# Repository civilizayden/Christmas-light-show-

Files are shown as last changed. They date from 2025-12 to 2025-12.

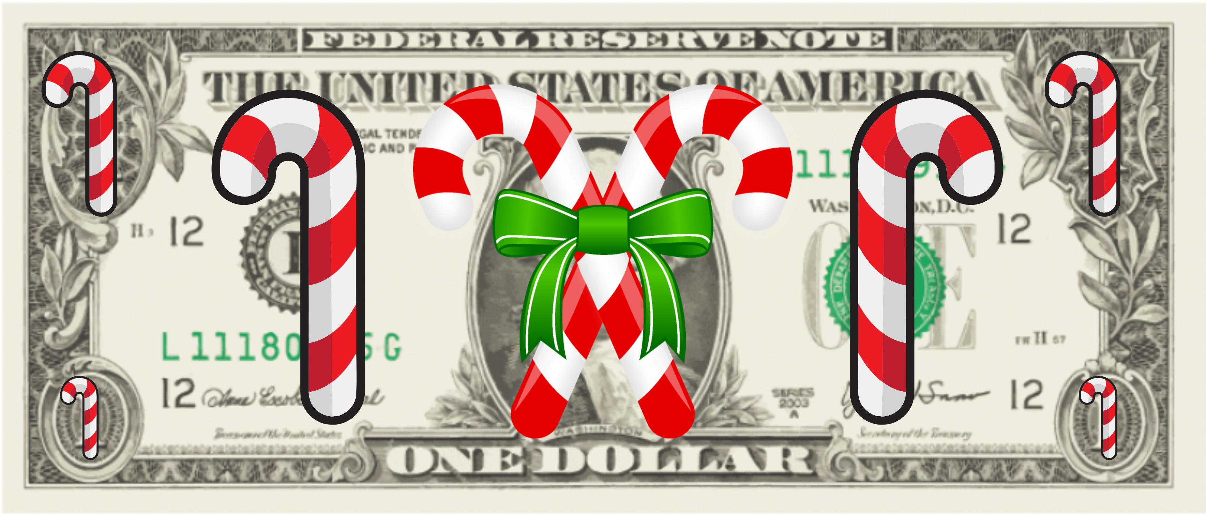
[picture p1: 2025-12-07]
Layout and Xlights config/ImportedMedia/The Elf Song/Images/Candy Cane Wages.png

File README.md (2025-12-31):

# Christmas light show
Light show  
Demo Video: https://youtu.be/NAZE_Fds844

# Description
5000 ws2811 pixels all synced to Christmas Music broadcasting over a radio transmitter. Includes 8 150 pixel candy canes, 3 talking coro props, 12 vertical strips outlining the house, pixels lining both the upper and lower eaves, 3 arches, 3 misc. coro props, and more. This year, there are 6 songs and intros to go along with them. Check out the rest of the info on the first journal entry on Blueprint! https://blueprint.hackclub.com/projects/2889 
# Files
I made all of the 3D files in onshape. Here's the links. I also uploaded them in .STEP format if you prefer that.  
  
WS2811 C9 clip-on: https://cad.onshape.com/documents/8e1d7c661a392a3fe8e3e552/w/2b79da62459af95523f34f54/e/d7efcc39778d9abc5af3c911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  
  
Vinyl J-Channel mount: https://cad.onshape.com/documents/51a32ab9cf6896e0ba53c2dc/w/2990cc1af5a4b7a38f5fad82/e/b13150ecd5dd56c7a36f59c3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  
  
PVC Clips: https://cad.onshape.com/documents/375a82727fe5ef4efe572c79/w/5d09f987b7f6cf59758c8e57/e/284350d5c3d51f49c312d2c3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  


# BOM
I made the BOM in a google sheet, so I'll link it here as well as upload the exported file.  
Updated BOM (No prices) https://docs.google.com/spreadsheets/d/1Xa2EI2wlwdVwfPyok5QENcuQ3c6ftch68BoIPOs7dK0/edit?usp=sharing  

What I bought (and planned future years) https://docs.google.com/spreadsheets/d/11jQSqjK9UyYTpo5pdGDNUm04ESjPkl9dXwzr9_6BSaI/edit?usp=sharing

# Helpful Links
https://xlights.org/ (Where the software I use comes from)  
https://drive.google.com/drive/folders/0B2ozCEidtWh3MUVzX0ZMc1pzY00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 (Where some of the pre-timed sequences come from)    
https://www.youtube.com/@How2Pixel  
https://www.youtube.com/@LearnChristmasLighting  
https://www.wiredwatts.com/power-calculator?srsltid=AfmBOoqk16NR0v8PqQ3Z4cDig1-WHCPIHeh7d5umanBR-S5C9AF-Xj1H  
http://spikerlights.com/calcpower.aspx  
# Pixel Controller
This is an explanation of the Falcon F48, which is the controller that I used to run my light show. The F48 is a differential transmitter board. Basically what this means is that the pixels don’t have to be next to the controller, you just have to have a receiver board near the pixels to connect them to. You connect via an Ethernet cable with an RJ45 connector.  
  
Each receiver board has four ports, which have a limit of 704 pixels per port in 48-port mode if you want to run your show at 40fps. However, the max you can run without power injection on one port is 300 pixels. There are 3 banks of pixels on the F48 which can be configured to share up to 1024 pixels, so max of bank1 + max of bank2 + max of bank3 cant exceed 1024.  
  
You can also configure the receiver board to do daisy chaining, meaning instead of running a length of Ethernet cable all of the way back to the F48, you can run one to the first receiver, then from one receiver to the next. You can chain up to 3 receivers off of one cable, but this has the disadvantage of requiring you to split the number of pixels per port across the chained boxes. For example, if you have 704 pixels per port on that chain, spot 1a + spot 1b has to be less than or equal to 704, rather than just having 704 pixels on spot one.  
  
The F48 is connected to a raspberry pi running a software called falcon pixel player (FPP), which controls the show’s start and stop times, and allows me to control it via a handy web UI. This also stores the sequences, which are outputted from Xlights.  
 

# Control Boxes
The way I have my boxes wired is simple, yet difficult to assemble if your pigtails are not long enough. I use xconnect pigtails to connect the pixels to the boxes and to each other. The Xconnect pigtail is currently the standard for light displays like mine.  
  
The boxes that are not used for daisy chaining have 6 ports, including the RJ45 input, the power input, and four pixel outputs. The boxes which are daisy chained have an additional RJ45 output. It is wired as shown, with the bottom pigtail on the outside being port one and the top one being port four. I use 12V 30A power supplies in my boxes, with the exception of the one used by the candy canes, which is 50A. 
 

# History
  There is a lot to catch up on. I want to document this project in at least some detail because of how long I have been working on it. This project has taken me the better part of two years, and has been a lot of fun and work. Because Blueprint only started this October, I am only going to be logging the hours since then, even though this log will also be going into detail about everything I have done before then. I will break this project down into the sections that I have done, not necessarily in chronological order.  
  
  The first thing I have done is learn how to build this in the first place. I first learned about this hobby when I was really young, going to a local Christmas light show. They have since moved away, leaving me with one option: to build my own. Thankfully, my uncle who lives on the other side of the country built one himself, so he has been a big help answering any questions I have had along the way. I started by watching big light shows from people like Tom BetGeorge. Then, I went to figure out how they were done. I watched videos on YouTube from AboveChristmasLighting and How2Pixel. I found out that I needed to use Xlights to set up and plan my layout, then program it all. I spent a week or so 3D modeling my house in SketchUp (the program that I was using anyway for my architecture and engineering class), and imported it into Xlights. For year one, I had the eaves, the front window, my gate, and my garages outlined in pixels. I also had a “singing” Rudolph coro prop and some arches. Year one xlights layout: 
  Year two layout: 
  
 Next up is putting up the eaves. After a lot of research I found that the way that I wanted to do it was by drilling holes in vinyl J-channel to push pixels through. (I use exclusively WS2811 pixels). I designed and 3D printed mounts which screw into my eaves to hang the J-channel, which also allow me to slide it out of view during the Christmas season. My dad and I borrowed my grandfather’s neighbor’s drill press (won’t be the last time) to drill the holes. We then stuck the pixels through, wired it up, and hung it.
  
  Another thing that I had to do was the garages and windows. My mother’s requirement for the show is that it had to have C9-style lights, which is difficult because they do not sell the type she likes with embedded smart pixels. So, I spent some time researching and designing a C9-style bulb which clips onto a WS2811 pixel. The final design is a simple revolve around a profile, 3D printed with fuzzy skin. It snaps onto a pixel, and then it is glued in place into a hole in a PVC pipe (drilled again with the drill press). Then I had to find a way to secure the PVC pipe to the house.
  
  This was a great difficulty, as there was no easy preexisting way to do this. I settled on two methods: magnets and standoffs for the windows and slide-in pucks for the garages. The puck has two countersunk holes for screws to be screwed into the house. You slide in a pvc clip/holder to the puck when you need to put up the lights, then click the PVC into the clip. For the window frames, I had to get creative, as I cannot drill into these. I ended up getting some adhesive metal strips, intended for the backs of phones for magnetic car mounts, and painting them white. I then bought magnets and designed another version of my clip which has a hole in the bottom for the magnet to screw into. I also designed some standoffs with flat bottoms for most of the weight to sit on the windowsill. Now my PVC frames easily clip onto the house, both for the garages and all of the window frames.
  
  I also had to have a way to control the pixels. I used the Falcon F48 and its differential receiver boards (thanks to my Uncle for gifting me that). I used 30cal ammo cans, a 12V 15A PSU, and the receiver board all in one box. The newest version of boxes that I build have four outputs of Xconnect pigtails, which are a standard to connect to all of the props I built. The boxes also have ethernet passthrough, since the receiver boards interface with the main controller board through standard ethernet cables. These boxes collectively control all of the props. I have around 8 boxes in use and 2 extras. One of my boxes has a 50A power supply and an automotive fuse block to safely control 1,200 pixels by itself (the candy canes). Additionally, I have a Raspberry Pi running Falcon Pixel Player (FPP) which is used to store the sequences and schedule them to start and stop at the right time, telling the F48 to do and when. I tell Xlights what pixel props are on what ports of the F48, then the software does the heavy lifting to render the sequences and output them to the pixels at 40fps.
  
  I had to make a lot of wires to connect everything to the boxes. To make the wires, I used whatever wire I found laying around as well as some 18 3 wire I bought specifically for this project. Xconnect pigtails were soldered to the wires using 3 heat shrink solder sleeves each and some heat shrink to finish it all off. I think I had around 50 of these that had to be made, not to mention all of the spots where I had to solder the pigtails to the pixels themselves or the pixel-to-pixel connections. Making the wires was a painstaking process, especially since I had to strip every single pigtail wire as well since I bought the cheapest pigtails I could find.
  
  Another thing I had to do was the Coro Props. I 3D printed myself a pixel pusher to push pixels into the high-density props without destroying my fingers. There were many props, and many pixels to push. I bought all of my props except for two from GilbertEngineeringUSA. The two that I didn’t buy, I made, since I bought 6 candy canes from them, then decided that I wanted two more to have an octave of candy canes. Those took a few days by themselves. I then had to mount the coro props. For the hanging coro props, I used PEX tubing to make a frame, then hung them from i-hooks drilled into my eaves with white paracord. The candy canes, arches, and tune-to sign use rebar hammered into the ground with PEX zip-tied to the props so that they slide onto the rebar.
  
  I also had to build the verticals. I used a jig and my pixel pusher to push the pixels into megatree pixel strip, which I then mounted to the house with i-hooks and zip ties. To secure them, I used stakes in the ground, weights on the concrete, and screws into the roof.
  
  There was also all of the programming. I will not go into much detail here, but I used Xlights and a bunch of community sequences (as well as some I got from my Uncle) to program the show. I recorded voiceovers of my family to give the coro props some character between songs, and programmed the lyric tracks for that as well as some of the community sequences I used. There were a few days of troubleshooting before I started up the show this year, which took a few days.
  
  All in all, since October, I have made all of the wires, rebuilt most of the boxes, mounted all of the coro props/verticals, put up all of the props, 3D printed replacement bulb covers, wired up all of the props, programmed the sequences, programmed the intro, bridges, and outro, exported the sequences, made all of the hardware play nice, troubleshooted, and started up the show. In total, I have probably spent over 250 hours on this project thus far, with around 50 of those being in the past two months to get this show conpleted.

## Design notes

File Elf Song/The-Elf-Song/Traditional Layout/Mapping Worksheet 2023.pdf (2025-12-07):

Showstopper Sequences Mapping Worksheet (2023)

Showstopper Group/Model Name | To Map to Your Group/Model Name
01.1.0AGrp EVERYTHING BUT STARBURST OVER RIDE 01.1.0BGrp EVERYTHING BUT STARBURST AND MATRIX OVER RIDE 01.1.1Grp FPG STARBURST
01.1.2Grp FPG MEGA TREE
01.1.3Grp FPG MATRIX
01.2.0Grp EVERYTHING BUT MEGA TREES STAR STARBURST GLOBE 01.3.0Grp HOUSE LESS YARD
01.4.0Grp HOUSE OUTLINE
01.4.1Grp ROOFLINE
01.5.0Grp ALL ARCHES
01.6.0Grp ALL CANDY CANES
01.7.0Grp ALL ICICLES
01.7.1Sub Icicle Tips
01.7.2Sub All Tips
01.7.3Sub Big Drops
01.8.0Grp ALL MINI TREES
01.9.0Grp ALL SNOWFLAKES
01.9.1Sub Snowflakes Arms
01.9.2Sub Snowflakes Center Stars 01.9.3Sub Snowflakes Tips
01.9.4Sub Snowflake Spokes 01.9.5Sub Snowflake Outlines 01.10.0Grp ALL STARS
01.11.0Grp HORIZONTALS
01.12.0Grp HOUSE MATRICES
01.13.0Grp YARD OUTLINE
01.14.0Grp VERTICALS
01.15.0Grp WINDOWS
02.0AGrp LEFT YARD
02.1.0Grp CANDY CANES YARD 02.1.1Sub Candy Canes Yard Outline 02.1.2Sub Candy Canes Yard Center 02.1.3Sub Candlestick
02.1.4Sub Flame
02.1.5Sub Cane Arches 1
02.1.6Sub Cane Arches 2
02.1.7Sub Cane Arches 3

Showstopper Group/Model Name | To Map to Your Group/Model Name
02.2.0Grp ARCHES TRIPLE
02.2.1Sub Arches Triple Top Arch 02.2.2Sub Arches Triple Middle Arch 02.2.3Sub Arches Triple Bottom Arch 02.3.0Grp TWIG TREE
02.4.0Grp OUTLINE LEFT YARD 02.5.0AGrp LEFT HOUSE
02.5.0Grp MATRICES GARAGE WINDOW 02.6.0Grp GARAGE DOOR
02.7.0Grp SPINNERS
02.7.10Sub Spinners Outer Third (V) 02.7.1Sub Spinners Outer Rings 02.7.2Sub Spinners Large All Rings 02.7.3Sub Spinners Large All Spokes 02.7.4Sub Spinners Small All Rings 02.7.5Sub Spinners Small All Spokes 02.7.6Sub Spinners All Rings 02.7.7Sub Spinners All Spokes 02.7.8Sub Spinners Inner Third (V) 02.7.9Sub Spinners Middle Third (V) 02.8.0GRP SNOWFLAKES GARAGE SMALL
02.8.1Sub Snowflakes Garage Small Arms 02.8.2Sub Snowflakes Garage Small Center Lines 02.8.3Sub Snowflakes Garage Small Inner Rings 02.8.4Sub Snowflakes Garage Small Spokes 02.8.5Sub Snowflakes Garage Small Tips 02.9.0Grp SNOWFLAKES LLS
02.9.1Sub Snowflakes LLS Arms 02.9.2Sub Snowflakes LLS Large Stars 02.9.3Sub Snowflakes LLS Inner Stars 02.9.4Sub Snowflakes LLS Middle Stars 02.9.5Sub Snowflakes LLS Outer Circles 02.9.6Sub Snowflakes LLS Tips 02.10.0Grp SPIRAL TREES
02.11.0AGrp RIGHT HOUSE
02.11.0Grp MATRICES DOOR COLUMN 02.12.0Grp SNOWFLAKES ROOF SMALL 02.12.1Sub Snowflakes Roof Small Arms

02.12.2Sub Snowflakes Roof Small Stars 02.12.3Sub Snowflakes Roof Small Tips 02.13.0Grp CANDY CANES HOUSE 02.13.1Sub Candy Canes House Center 02.13.2Sub Candy Canes House Outline 02.13.3Sub House Cane Arches 1 02.13.4Sub House Cane Arches 2 02.13.5Sub House Cane Arches 3 02.14.0Grp FLOODS
02.15.0AGrp RIGHT YARD
02.15.0Grp MINI TREES MID SIZE 02.16.0Grp MINI TREES SMALL 02.17.0Grp STARS MINI TREES 02.17.1Sub Star Outline
02.17.2Sub Star Inner Spinner 02.17.3Sub Star Arm Spinner
02.18.0Grp ARCHES RIGHT YARD
02.19.0Grp SNOWFLAKES RIGHT ARCH 02.19.1Sub Snowflakes Right Arch Arms 02.19.2Sub Snowflakes Right Arch Stars 02.19.3Sub Snowflakes Right Arch Tips 02.20.0Grp PIXEL POLES
02.21.0Grp STARS PIXEL POLES
02.21.1Sub Star All Points
02.21.2Sub Star Candle Flames 02.21.3Sub Star Inner Spinner 02.21.4Sub Star Arm Spinner 02.21.5Sub Star Outline
02.24.0Grp GROUND SPINNER
02.24.1Sub Ground Spinner Rings 02.24.2Sub Ground Spinner Spokes 02.25.0Grp SNOWFLAKES ALL HOUSE 02.26.0Grp OUTLINE RIGHT YARD 02.27.0Grp SPIN ARCHES
02.27.1Sub Spokes
02.27.2Sub Short Spokes
02.27.3Sub Matrices
02.27.4Sub All Arches

02.27.5Sub Burst
02.27.6 Sub Swirls (CW)
02.27.7Sub Swirls (CCW)
02.27.8Sub Fireworks
02.27.9Sub Crosses
02.27.10Sub Big Crosses
02.27.11Sub Diamonds
02.27.12Sub Hearts
02.27.13Sub Flowers
02.27.14Sub Individual Arch 4 02.27.15Sub Full Burst
03.1.0Mod STARBURST
03.2.0Mod Peace Stakes
03.2.1Sub Peace Stakes Even 03.2.2Sub Peace Stakes Odd 03.3.0Mod MEGA TREE 16 x 50 03.4.0Mod MEGA TREE 32 x 160
03.5.0Mod TREE SPHERE
03.6.0Mod PPD WREATH
03.6.1Sub PPD Wreath Diamond Arms 03.6.2Sub PPD Wreath Valleys 03.6.3Sub PPD Wreath Center Piece 03.6.4Sub PPD Wreath Center Rings 03.6.5Sub PPD Wreath Outer Diamonds 03.6.6Sub PPD Wreath Spiral All 03.7.0Mod GE ROSA WREATH
03.8.0Mod LARGE MATRIX 1
03.9.0Mod LARGE SNOWFLAKE
03.10.0Mod INVERTED MEGA TREE 03.11.0Mod WINDOW WREATH
03.12.0Mod MEGA TREE STAR
03.13.0Mod TUNE TO SIGN
03.15.0Mod Showstopper Snowflake 03.16.0Mod Showstopper Spinner

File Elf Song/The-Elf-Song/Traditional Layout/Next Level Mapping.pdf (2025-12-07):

## Level 1 - Whole Display

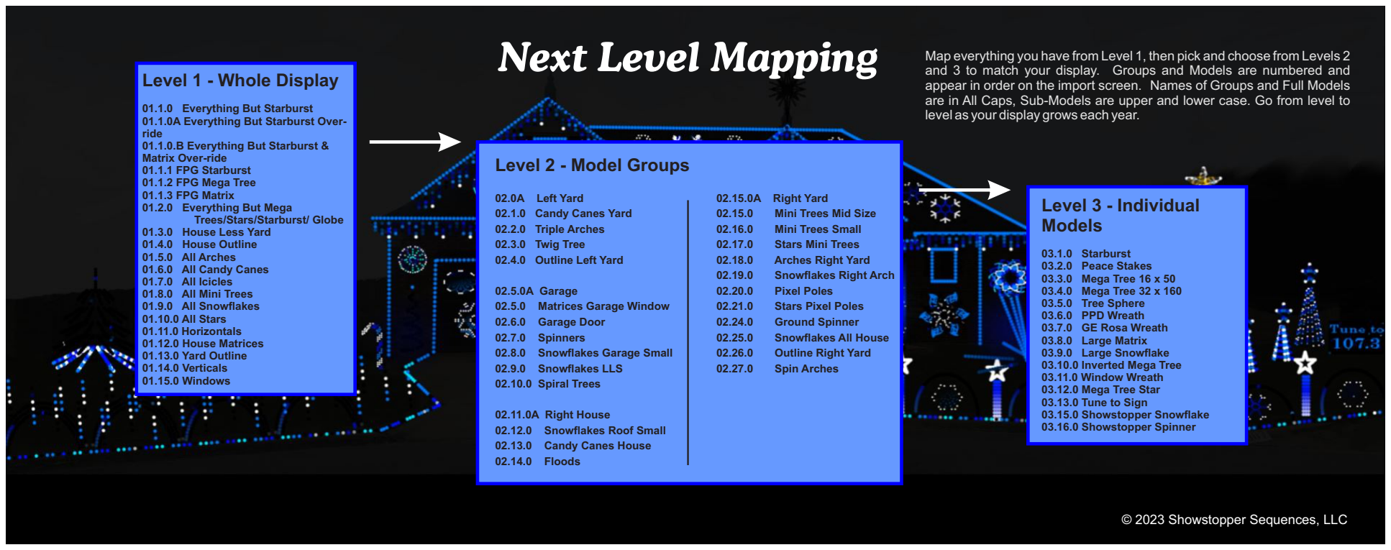
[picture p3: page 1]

### 01.2.0 Everything But Mega

### 01.1.2 FPG Mega Tree

### 01.1.1 FPG Starburst

### 01.1.3 FPG Matrix

### 01.1.0 Everything But Starburst

01.1.0A Everything But Starburst Over-ride
01.1.0.B Everything But Starburst & Matrix Over-ride

### 01.12.0 House Matrices

### 01.10.0 All Stars

### 01.15.0 Windows

### 01.6.0 All Candy Canes

### 01.5.0 All Arches

### 01.14.0 Verticals

### 01.8.0 All Mini Trees

### 01.7.0 All Icicles

### 01.3.0 House Less Yard 01.4.0 House Outline

### 01.9.0 All Snowflakes

### 01.11.0 Horizontals

### 01.13.0 Yard Outline

Trees/Stars/Starburst/ Globe

### 03.8.0 Large Matrix

### 03.10.0 Inverted Mega Tree

### 03.12.0 Mega Tree Star

### 03.4.0 Mega Tree 32 x 160

### 03.6.0 PPD Wreath

### 03.5.0 Tree Sphere

### 03.1.0 Starburst

### 03.7.0 GE Rosa Wreath

### 03.9.0 Large Snowflake

### 03.11.0 Window Wreath

### 03.16.0 Showstopper Spinner

### 03.2.0 Peace Stakes

### 03.15.0 Showstopper Snowflake

## Level 3 - Individual Models

### 03.3.0 Mega Tree 16 x 50

### 03.13.0 Tune to Sign

### 02.6.0 Garage Door 02.7.0 Spinners

### 02.12.0 Snowflakes Roof Small

### 02.10.0 Spiral Trees

### 02.2.0 Triple Arches

### 02.4.0 Outline Left Yard

### 02.1.0 Candy Canes Yard

### 02.13.0 Candy Canes House

### 02.9.0 Snowflakes LLS

### 02.8.0 Snowflakes Garage Small

### 02.3.0 Twig Tree

02.0A Left Yard

02.5.0A Garage

### 02.5.0 Matrices Garage Window

## Level 2 - Model Groups

02.11.0A Right House

### 02.14.0 Floods

### 02.21.0 Stars Pixel Poles

### 02.26.0 Outline Right Yard

### 02.25.0 Snowflakes All House

### 02.27.0 Spin Arches

### 02.24.0 Ground Spinner

### 02.20.0 Pixel Poles

02.15.0A Right Yard

### 02.15.0 Mini Trees Mid Size 02.16.0 Mini Trees Small

### 02.19.0 Snowflakes Right Arch

### 02.18.0 Arches Right Yard

### 02.17.0 Stars Mini Trees

Next Level Mapping Map everything you have from Level 1, then pick and choose from Levels 2

### and 3 to match your display. Groups and Models are numbered and appear in order on the import screen. Names of Groups and Full Models are in All Caps, Sub-Models are upper and lower case. Go from level to

level as your display grows each year.

### © 2023 Showstopper Sequences, LLC

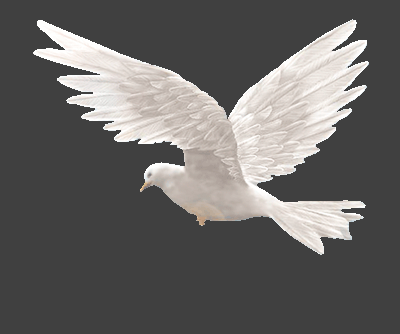
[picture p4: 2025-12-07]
Christmas Every Day/Media/Dove3.gif

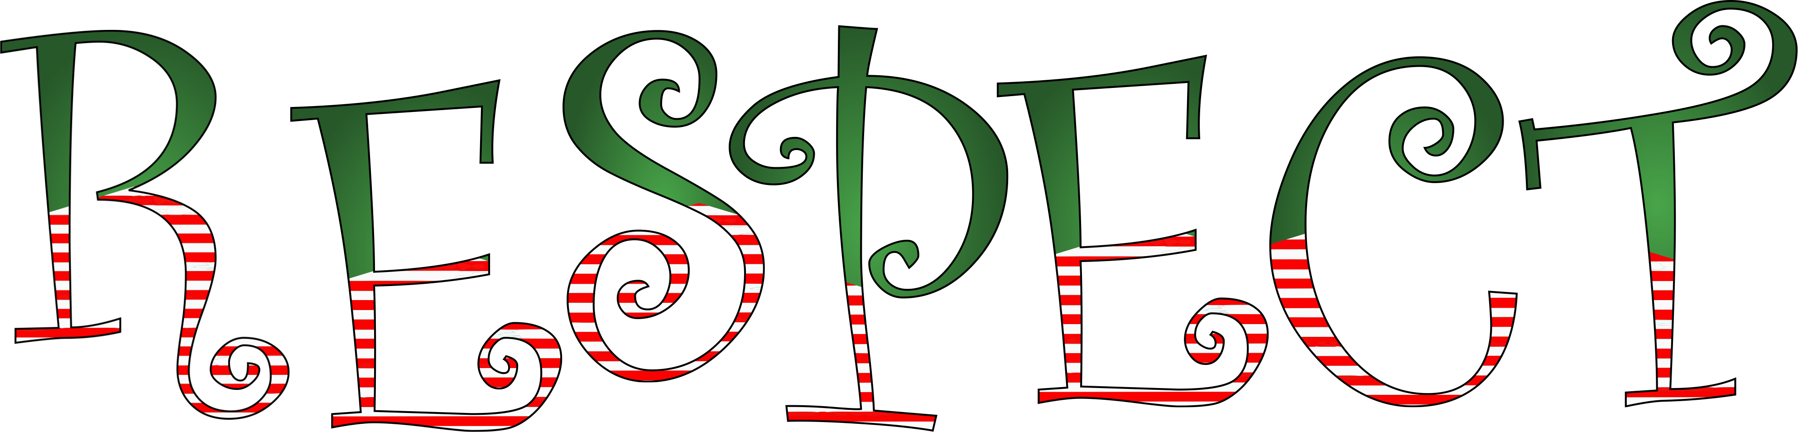
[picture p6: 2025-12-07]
Layout and Xlights config/ImportedMedia/The Elf Song/Images/Respect.png

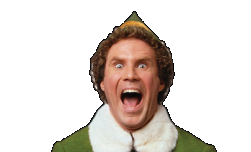
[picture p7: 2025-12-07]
Layout and Xlights config/ImportedMedia/The Elf Song/Images/Buddy.png

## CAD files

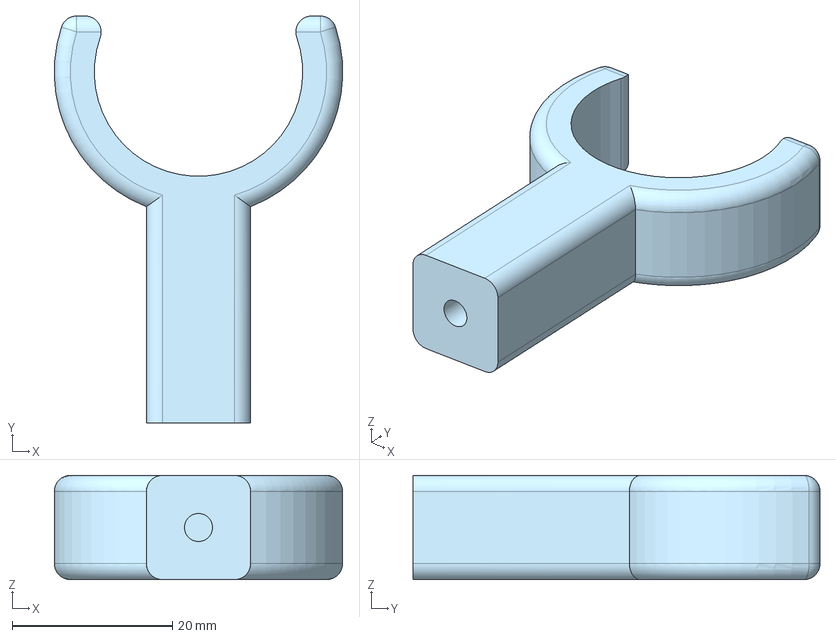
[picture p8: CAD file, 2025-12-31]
3D Files/PVC Mounts/Pole Holder Magnet 1.step
36.0 x 50.8 x 13.0 mm

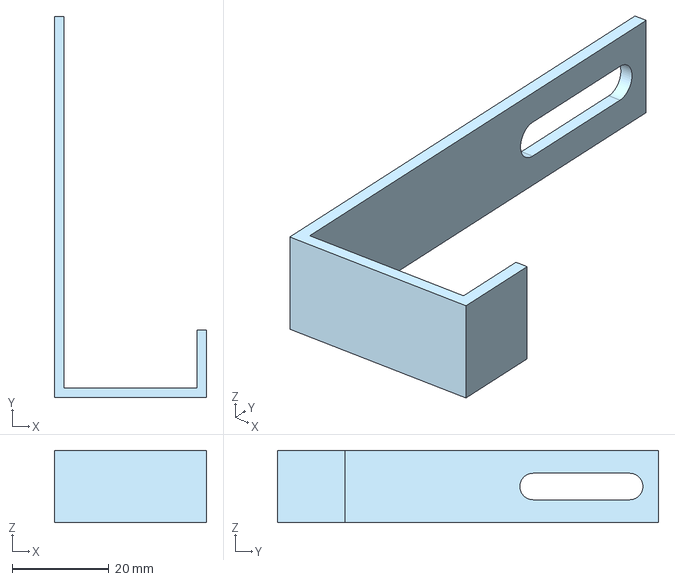
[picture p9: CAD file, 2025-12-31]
3D Files/Vinyl Mount.step
31.5 x 79.0 x 15.0 mm

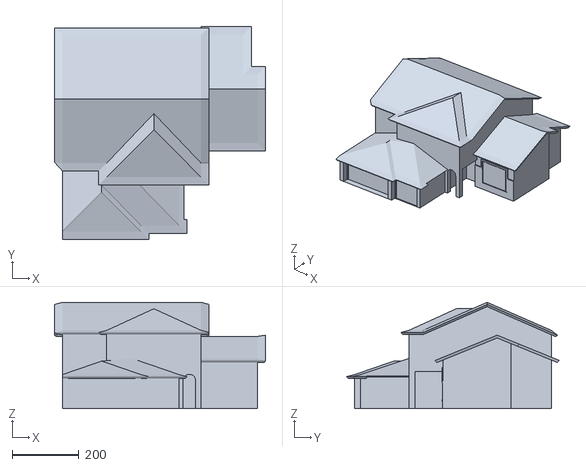
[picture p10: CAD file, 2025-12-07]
Layout and Xlights config/3D/ImageToStl.com_house.obj
630.5 x 636.0 x 318.0

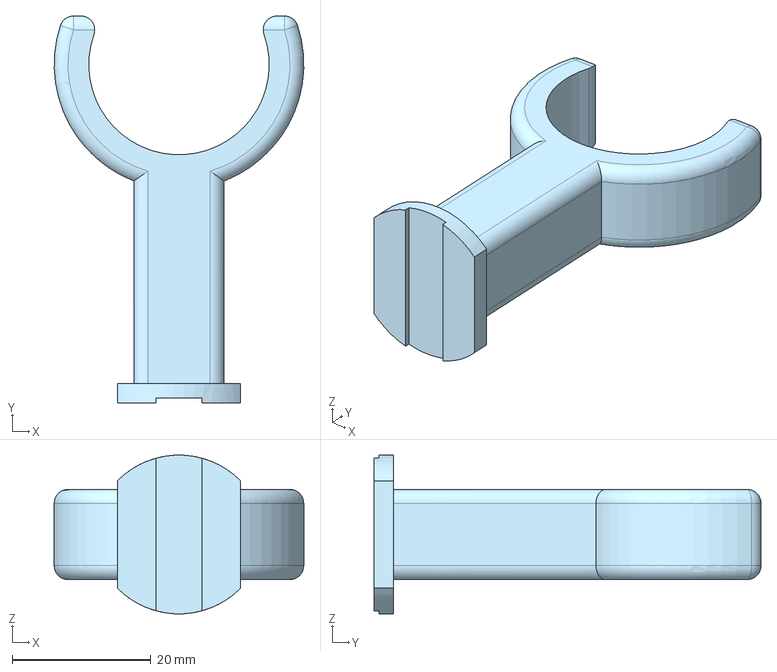
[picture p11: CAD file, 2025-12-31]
3D Files/PVC Mounts/Pole Holder Puck Version.step
36.0 x 55.8 x 22.9 mm

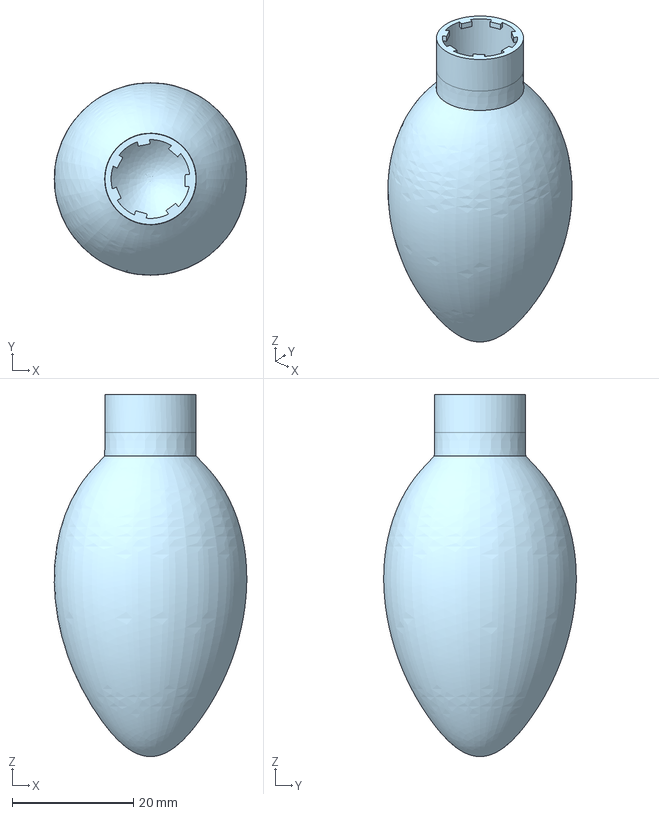
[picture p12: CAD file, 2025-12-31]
3D Files/WS2811 C9 Clip-on.step
31.7 x 31.7 x 59.7 mm

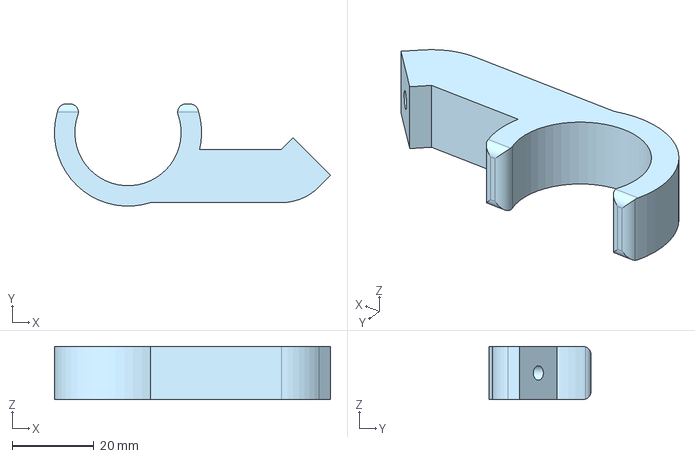
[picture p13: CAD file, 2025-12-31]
3D Files/PVC Mounts/Pole Holder Magnet angled.step
67.5 x 25.0 x 13.0 mm

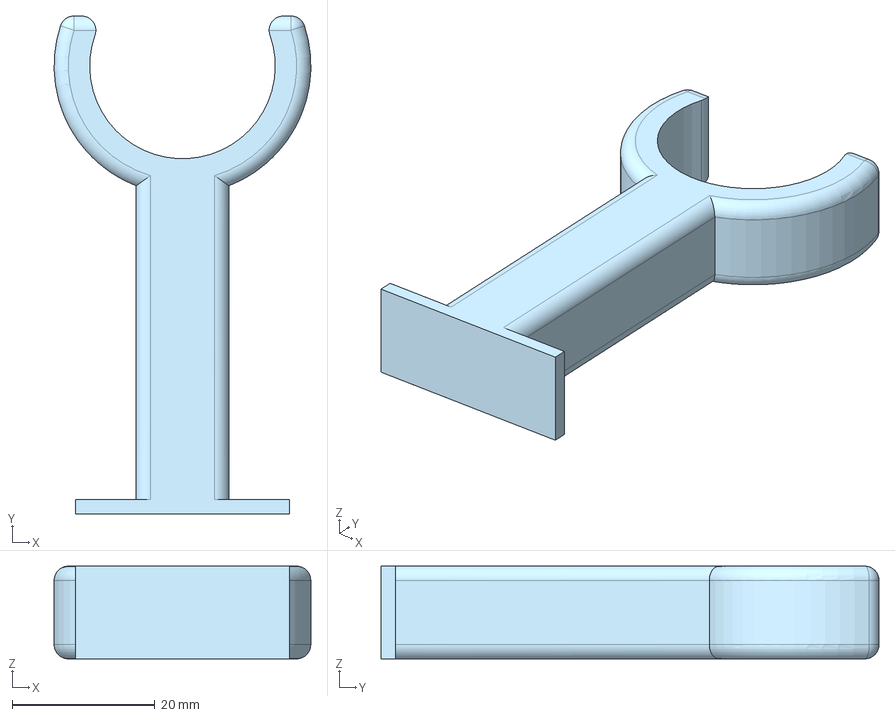
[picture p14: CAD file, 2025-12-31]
3D Files/PVC Mounts/Pole Holder Flat Bottom.step
36.0 x 69.8 x 13.0 mm

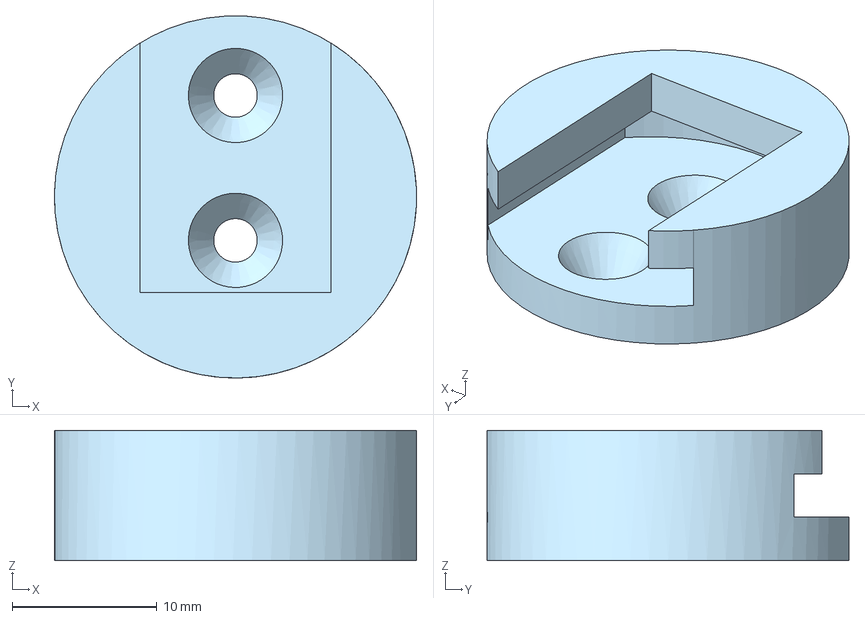
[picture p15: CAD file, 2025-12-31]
3D Files/PVC Mounts/Pole Holder Puck.step
25.0 x 25.0 x 9.00 mm

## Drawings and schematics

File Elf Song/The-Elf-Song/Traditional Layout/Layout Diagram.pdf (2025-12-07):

# Showstopper Sequences

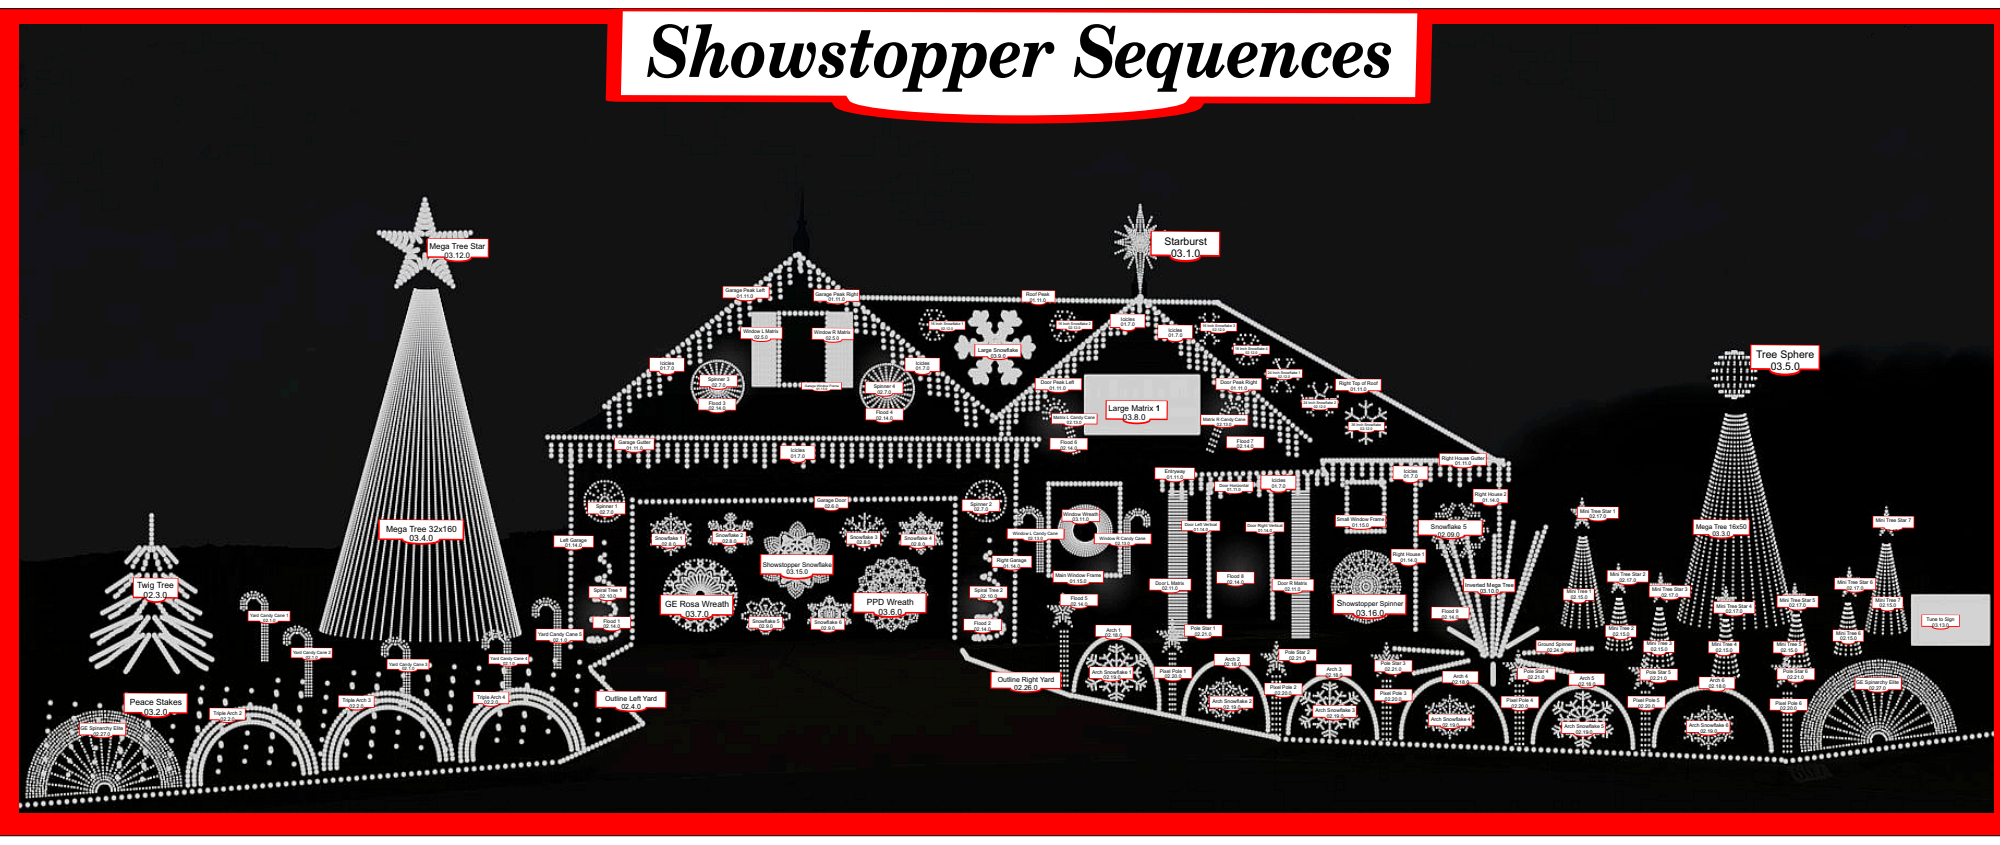
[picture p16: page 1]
Mega Tree 32x160 03.4.0; Tree Sphere 03.5.0; Twig Tree 02.3.0; Yard Candy Cane 3; Triple Arch 2 02.2.0; Triple Arch 3 02.2.0; Triple Arch 4; Outline Left Yard; 02.4.0 Peace Stakes 03.2.0; Snowflake 1 02.8.0; Snowflake 2 02.8.0; Snowflake 3 02.8.0; Snowflake 4 02.8.0; Snowflake 5 02.9.0; Snowflake 6 02.9.0; Garage Door 02.6.0; Icicles 01.7.0; Starburst 03.1.0; Large Matrix 1 03.8.0; Snowflake 5 02.09.0; Spiral Tree 1 02.10.0; Spiral Tree 2 02.10.0; Spinner 1 02.7.0; Spinner 2 02.7.0; Spinner 3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

Mega Tree Star

Garage Peak Left

Garage Peak Right

Door Peak Left

Door Peak Right

Right Top of Roof

Garage Window Frame

Matrix L Candy Cane

Matrix R Candy Cane

Right House Gutter

Mini Tree Star 1

Door Left Vertical

Small Window Frame

Mini Tree Star 7

Door Right Vertical

Window L Candy Cane

Window R Candy Cane

Main Window Frame

Mini Tree Star 2

Inverted Mega Tree

Mini Tree Star 6

Mini Tree Star 3

GE Rosa Wreath

Mini Tree Star 5

Mini Tree Star 4

Yard Candy Cane 1

Tune to Sign

Yard Candy Cane 5

Yard Candy Cane 2

Yard Candy Cane 4

Outline Right Yard

GE Spinarchy Elite
